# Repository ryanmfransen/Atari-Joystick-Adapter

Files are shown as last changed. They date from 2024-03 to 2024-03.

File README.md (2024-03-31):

# Atari Joystick Adapter
A bluetooth adapter for the Atari CX-40 joysticks

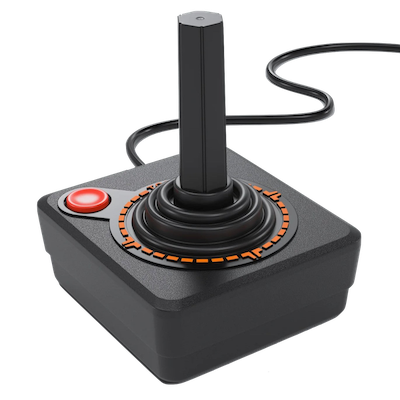
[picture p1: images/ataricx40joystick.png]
Atari CX-40 Joystick


## Finished Product

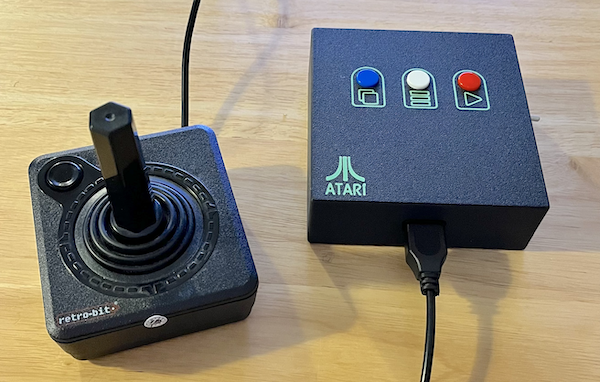
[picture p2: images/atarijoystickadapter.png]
Atari Joystick Adapter


## Design Objectives
You might ask why I would build such a project. With the proliferation of existing gamepads, retro tech, and alternatives, what is it about this that makes it unique?

Fair question. To begin, let's roll back the clock. I used to have all the old systems, and when I wanted to play any of the retro machines, I would simply toss in the cartridge and play away, just like when I was a kid.

I've since sold my collection of retro game machines and recently got into emulation. Emulation affords me the opportunity to still play the old school games yet be able to do so on a single, modern appliance. 

This is great, except for one thing; The joysticks.

I miss playing games as they were intended. It just isn't the same thing playing Space Invaders on the Atari 2600 with the classic joystick as it is playing it on an emulator with a modern XBox controller.  Yes, it works fine, but the experience is not the same.

The Atari Joystick Adapter was born. *I wanted a way to use my classic joysticks the way the games were designed for while playing emulation.*
## Design Goals
**Classic Joysticks**

I wanted to be able to use my existing class joysticks without modification.

**Wireless**

The adapter needed to be wireless, so I can sit back on my couch and play games without being tethered to an appliance.

**Emulator Navigation**

I needed ther ability to navigater, and control the emulator with the classic joystick such that I could select, launch and play games without the use of another controller, remote, or keyboard.

**Additional Game System Buttons**

I needed the ability to mimic the buttons on the original Atari to begin playing games - Start for example.

**Battery Operated**

To be truly wireless, I needed to make this a battery operated device, and be able to charge the device simply by plugging in a USB-C cable such as is with modern rechargeable devices.

**Professional**

Yeah yeah I know, this is a one off device but I want it to look professional, with a custom PCB, and a good looking multicolour 3D printed enclosure.

## The PCB

I designed the circuit using KiCad. I designed most of the symbols, and footprints, sans the simple capacitor, resistor, and connectors. I think I also grabbed the ESP32 symbol from somewhere. The schematics and the KiCad project files can be found here: [Atari Joystick Adapter KiCad Project](kicad/)

Schematic:

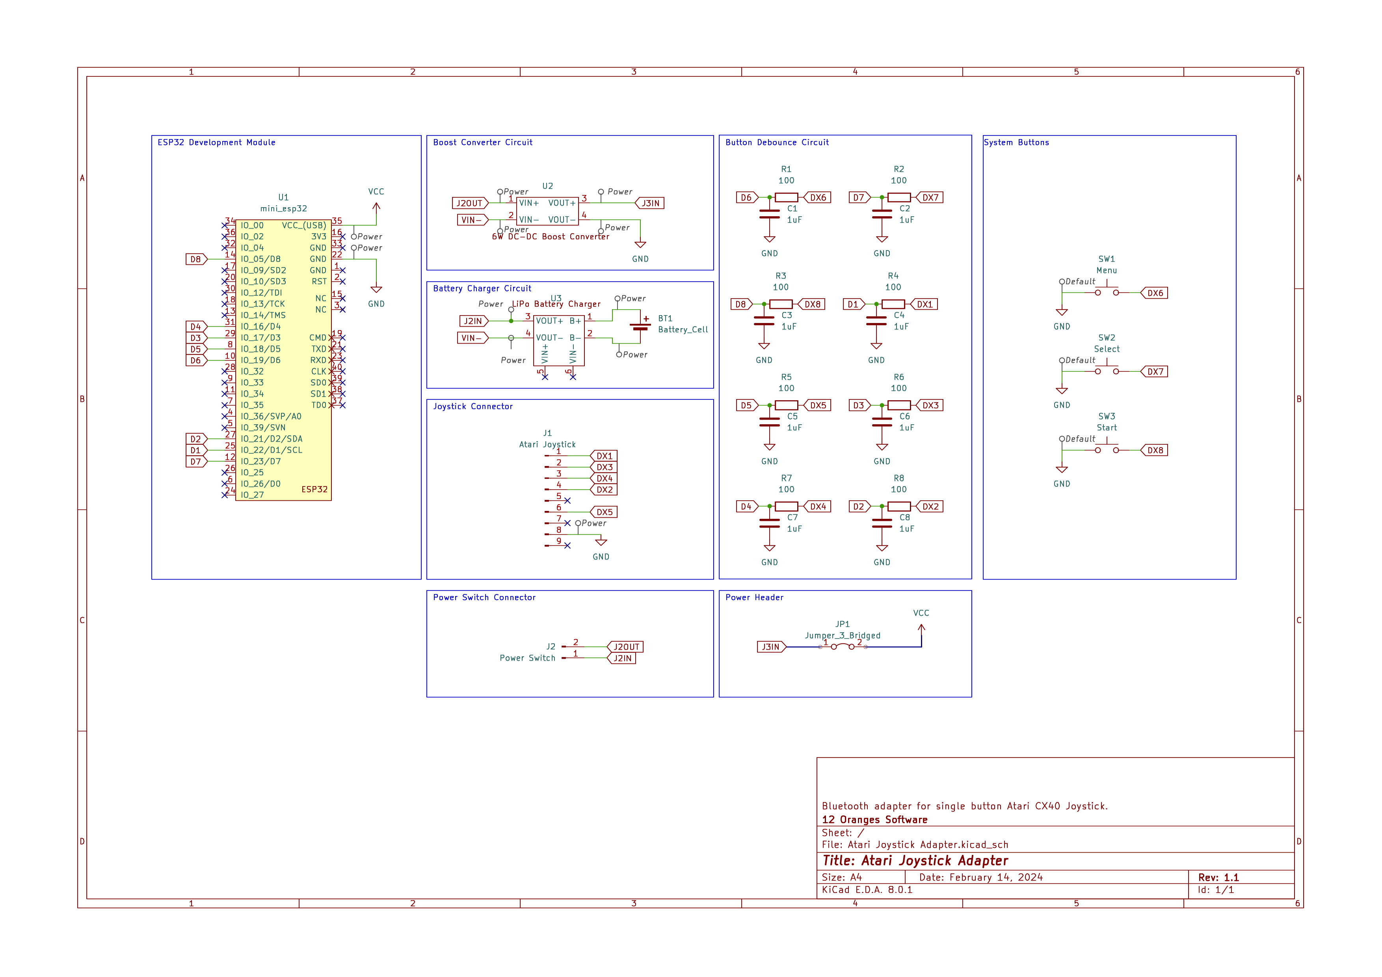
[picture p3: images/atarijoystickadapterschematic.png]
Atari Joystick Adapter Schematic


Here is a 3d Render (v1.1):

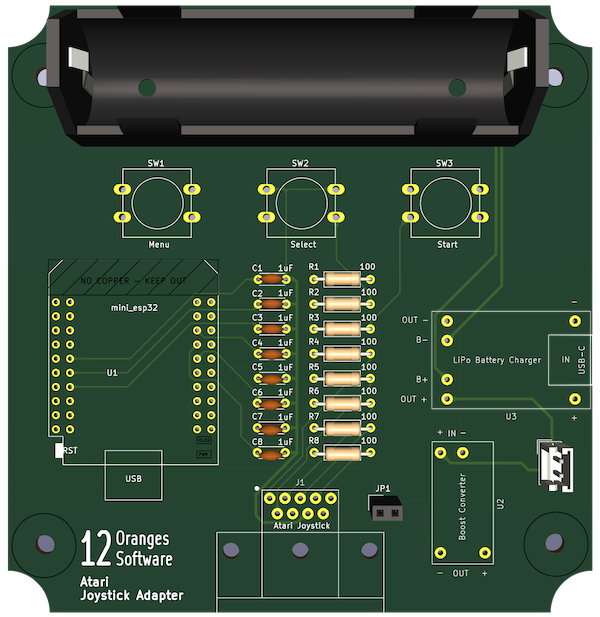
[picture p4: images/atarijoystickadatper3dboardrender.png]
Atari Joystick Adapter 3D PCB Render


Here is a picture of the populated board (v1.0)

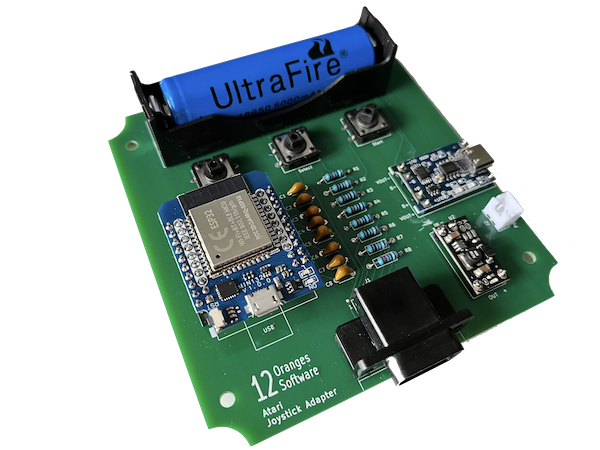
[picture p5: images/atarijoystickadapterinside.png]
Atari Joystick Adapter Inside


I sent the gerber files to PCBWay to be built, and received 10 boards in about a week.

## Interfacing the Atari Joystick

The Atari joystick uses a simple mechanism to manage the four direction buttons and the fire button.  Each button is assigned to a pin on the connector, and when pressed brings the pin low, as is seen from the ground, or common pin on the connector, pin eight(8). This makes it quite easy to connect to the ESP32, all I needed was simple debounce circuits and can otherwise go straight into the digital GPIO pins.

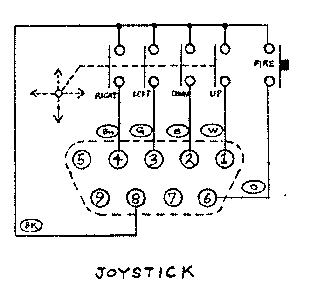
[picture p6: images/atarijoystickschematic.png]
Atari Joystick Schematic


## The Atari Connector

I recall back in the seventies and eighties we used to use standard DB9 serial connectors when we were making Atari style joysticks or interfacing to them. While these don't quite fit perfectly, they do work well. For this project I wanted to finally make use of real Atari joystick connectors, so I found a source for them in San Jose, Best Electronics, and bough 20 of them.

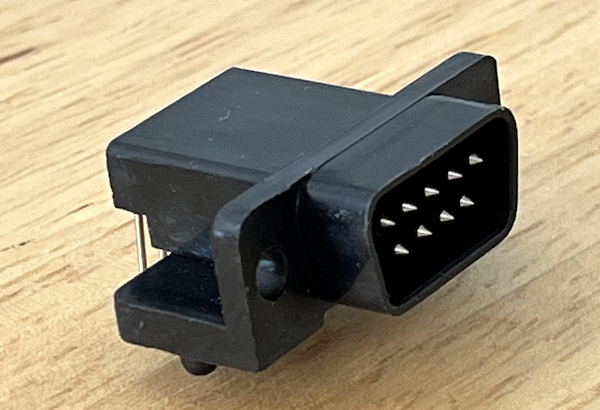
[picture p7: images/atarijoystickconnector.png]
Atari Joystick Connector


I've also modelled the Atari joystick connector in CAD.  Mostly just to help facilitate designing the enclosure for fitment, however I also added it to the KiCad footprint so you could also render the 3d model of the PCB with it as well.

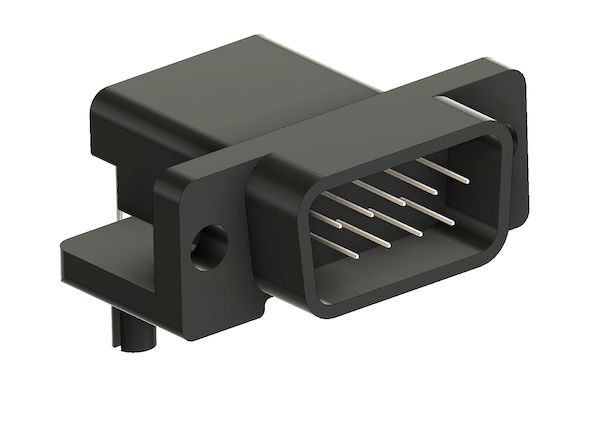
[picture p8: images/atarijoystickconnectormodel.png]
Atari Joystick Connector Model


You can download the model here: [Atari Joystick Connector Model](models/atarijoystickmodel.step)

## ESP32

I ended up using the ESP32 Mini WROOM-32 by KeeYees.  I really like the mini board configuration, as I have used several of the similar D1Minis ESP8266's in the past.

The ESP32 dev board was the obvious choice for this project as it has the bluetooth connectivity I need and sufficient GPIO pins.

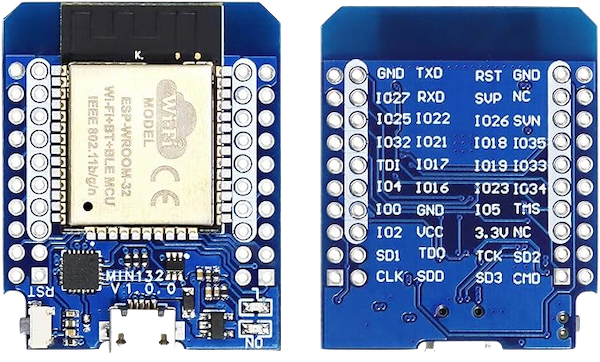
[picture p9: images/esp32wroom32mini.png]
ESP32 Mini


I used this ESP32 from Amazon: [ESP32 Mini Wroom-32](https://www.amazon.ca/gp/product/B08TBQRMY4)

## Battery and Battery Charging

One of my design goals was to use a rechargeable battery and circuit.  I had a bunch of 18650 batteries around for other projects, so that seemed like it would be a good fit for this project.  I would have to settle on a charging circuit, and I could obtain a TC4056 Lithium Battery Charger Module Board from Amazon for quite cheap.  This would more than suffice for what I needed.  The ESP32 uses a 5V input, so I needed to deal with this, as the 18650 has a 3.7v output, which does diminish during it's charge/release cycle.  A simple DC-DC 6W Mini Step-Up Boost Converter would do the trick, and boost me up to 5V, regardless of the diminishing voltage. Perfect - Both these parts are cheap and easily available.

At this point all I had to do was throw a switch into the power circuit and that should solve my power requirements. Done.

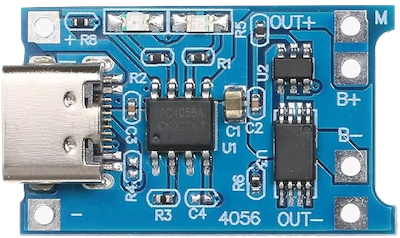
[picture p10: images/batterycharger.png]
Battery Charger


I purchased this [Battery Charger](https://www.amazon.ca/gp/product/B0B48VWHTD) from Amazon

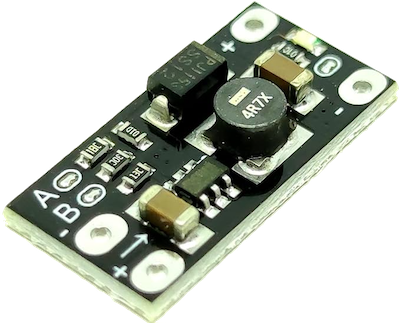
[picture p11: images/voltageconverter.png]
Volage Converter


I purchased this [Boost Converter](https://www.amazon.ca/gp/product/B09TZSGHYK) from Amazon

## Enclosure

I designed the enclosure in Autodesk's Fusion 360. I think it worked out quite well.  The enclosure consists of the main(top) piece, and the cover (bottom) as well as three switch extensions so you can use the three switches placed in the PCB such that they would extend the proper amount up and out of the top case.

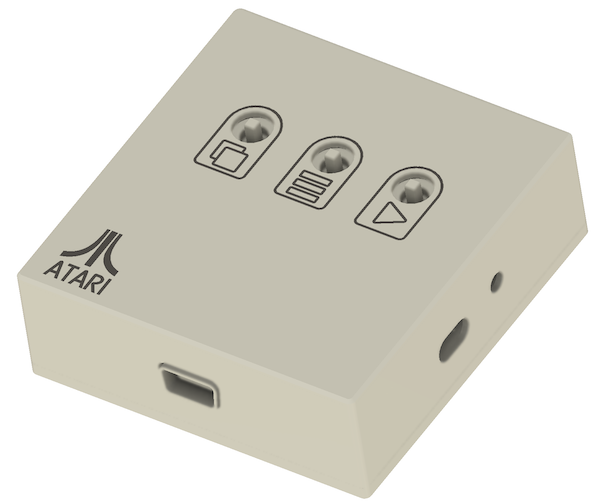
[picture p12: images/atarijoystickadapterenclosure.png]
Atari Joystick Adapter Enclosure Rendering


The enclosure CAD files can be found here: [Atari Joystick Adapter CAD Files](models)

The Bambu Studio .3mf file for the enclosure can be found here: [Atari Joystick Adapter Bambu Studio 3mf Project File](bambustudio/Atari%20Joystick%20Adapter%20Case.3mf)

## The Code

I built the code for this project in C++ using Visual Studio Code and PlatformIO, with the Arduino Framework.  I make use the GamepadBLE library by lemmingDEV, found here: [ESP-32-BLE-Gamepad](https://github.com/lemmingDev/ESP32-BLE-Gamepad)

I use a number of classes to manage the program.  The main class is the Button class.  The Button class encapsulates everything needed to support using buttons on your retro joysticks. It will store the current button state, whether the state has changed, which ESP32 GPIO pin the button is assigned to, and it handles the hardware interrupt callback for that button.  Each button manages it's own interup handler to encapsulate the interrupt logic. This class is used for the joystick, or d-pad (hat) direction buttons.

The second Class is the FireButton class, extending the Button class.  This adds in the addition of a button identifier, used for gamepad buttons, such as the fire button.

The interrupt service routines, in the button objects simply set the updated state, and flag the button as having changed state.

Managing the interrupt handler in each object is a handy way to control state. Most solutions I have seen out on Youtube have some sort of global variables storing the state for all the buttons.  I like the ability to do this atomically, it keeps things clean.

Here is the Button class initializer function, setting the ISR for the class instance.
```
void Button::init() {
  // Set the pin to input and use a pullup resistor
  pinMode(pin, INPUT_PULLUP);

  // Set the current state of the pin
  this->state = LOW;

  // Let's attach the interrupt handler
  std::function<void(void)> stdFunct {std::bind(&Button::instanceIsr, this)};
  attachInterrupt(digitalPinToInterrupt(this->pin), stdFunct, CHANGE);
}
```

The main loop of the application simply iterates over the button instances, checking if they have changed state.  If they have, then the new state is sent via the bluetooth gamepad.

The project code and all source files are included for you.

This project was built to accommodate the four joystick direction buttons, the single joystick fire button, as well as three additional buttons to support game system and emulator navigation and control.

The joystick direction buttons are mapped to the four hat buttons in the gamepad emulation.  The possible states are:

```
  LEFT_UP:8     UP:1          UP_RIGHT:2 
  ⎡    ▲    ⎤   ⎡    ▲    ⎤   ⎡    ▲    ⎤
  ⎢    0    ⎟   ⎢    0    ⎟   ⎢    0    ⎟
  ⎢◀︎ 0   1 ▷⎟   ⎢◁ 1   1 ▷⎟   ⎢◁ 1   0 ▶︎⎟
  ⎢    1    ⎟   ⎢    1    ⎟   ⎢    1    ⎟ 
  ⎣    ▽    ⎦   ⎣    ▽    ⎦   ⎣    ▽    ⎦ 
  
  LEFT:7        CENTERED:0    RIGHT:3
  ⎡    △    ⎤   ⎡    △    ⎤   ⎡    △    ⎤
  ⎢    1    ⎟   ⎢    1    ⎟   ⎢    1    ⎟
  ⎢◀︎ 0   1 ▷⎟   ⎢◁ 1   1 ▷⎟   ⎢◁ 1   0 ▶︎⎟
  ⎢    1    ⎟   ⎢    1    ⎟   ⎢    1    ⎟
  ⎣    ▽    ⎦   ⎣    ▽    ⎦   ⎣    ▽    ⎦
  
  DOWN_LEFT:6   DOWN:5        DOWN_RIGHT:4
  ⎡    △    ⎤   ⎡    △    ⎤   ⎡    △    ⎤
  ⎢    1    ⎟   ⎢    1    ⎟   ⎢    1    ⎟ 
  ⎢◀︎ 0   1 ▷⎟   ⎢◁ 1   1 ▷⎟   ⎢◁ 1   0 ▶︎⎟
  ⎢    0    ⎟   ⎢    0    ⎟   ⎢    0    ⎟
  ⎣    ▼    ⎦   ⎣    ▼    ⎦   ⎣    ▼    ⎦
```
Each state is mapped to an integer value, from `0..8` and it is this integer value sent to the gamepad controller to register the d-pad presses in the emulator.

The four buttons are buttons `1..4`, and are typically registered, depending on the system you pair with, as buttons a, b, x, y on the gamepad controller in the emulator.

From here, you can assign each of these four buttons to whatever makes sense for you.  I used:
```
[a], [b], [select], [start]
```

## Emulator

I use Retroarch, and it was a little tricky getting the proper button assignments configured so I could navigate the Retroarch menu, launch the game in the emulator, and then start the game, and play the game all with only using the Atari joystick and the buttons on the adapter.

Once configured, it works incredibly well.

## Did I achieve my Goals?

Yes! I believe so. Let's have a look:
- [x]  Classic Joysticks
- [x]  Wireless
- [x]  Emulator Navigation
- [x]  Additional Game System Buttons
- [x]  Battery Operated
- [x]  Professional

## Observations

1. Latency.  The latency is either incredible, or I am blind to it because I put so much effort into making this. In any event, gameplay is amazing, and very responsive.  I am very happy with the latency given the bluetooth connectivity, and emulation.

2. I actually use this.  Unlike most of my projects which are super fun to build, they usually end up on a shelf, or in a drawer, and I tend to forget about them. This project is different.  I actually is it, and is a lot of fun to play the games wit hthe classic controllers.

## What I Would do Different Next Time

1. Test Points. I would (and have in the v2 board) include test points to troubleshoot the circuit. This just makes things much easier to measure voltages and test your circuits.

2. Power Jumper. Ok, so I have to admit I placed all the parts, soldered everything in, and powered it on.  Of course, I forgot to configure the voltage booster from the default 12v to my required 5v, and I fried my brand new ESP32. 
 I've since added a two pin jumper that needs to be in place for the power to get to the ESP32, this way I can power the board up and test the circuit power without destroying the ESP.

3. My first prototype had the ESP32 soldered directly to the board, and while offers a nice finished product, see point 2 above, and I needed to remove it, so prototype two I put headers in and as you can see from the picture, the ESP32 is now removable, if ever needed.

4. While the 18650 works well, I might source a small flat pack lithium ion battery. The package is much smaller and will have plenty of power for what I need.  Would also remove the need for the battery holder I had to source.

## Next Steps

1. Driving Controller. I would like to support the Atari driving controller used for games like Indy 500.

2. Paddle Controllers. I would also like to support the Atari paddle controllers used for games like Super Breakout or Warlords.

3. Sega or Nintendo Controllers. Might be nice to extend this to use the controllers using shift registers or other multiplexers. Modern versions of these controllers can be purchased, so uncertain about this.

4. Two Player support. At the moment, this is a device for a single Atari joystick. Perhaps I could extend this to support two joysticks for two player games without requiring two devices.

## Contact Me!

If you would like to discuss the project or have an idea, or question please reach out.  I can be reached at:

`ryan.fransen[the symbol for at]me.com`

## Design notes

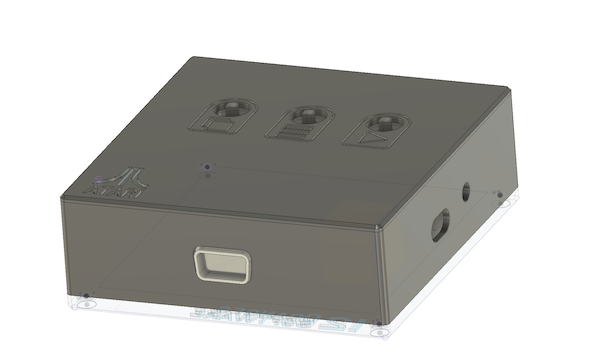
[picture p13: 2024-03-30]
images/atarijoystickadaptercaserender.png

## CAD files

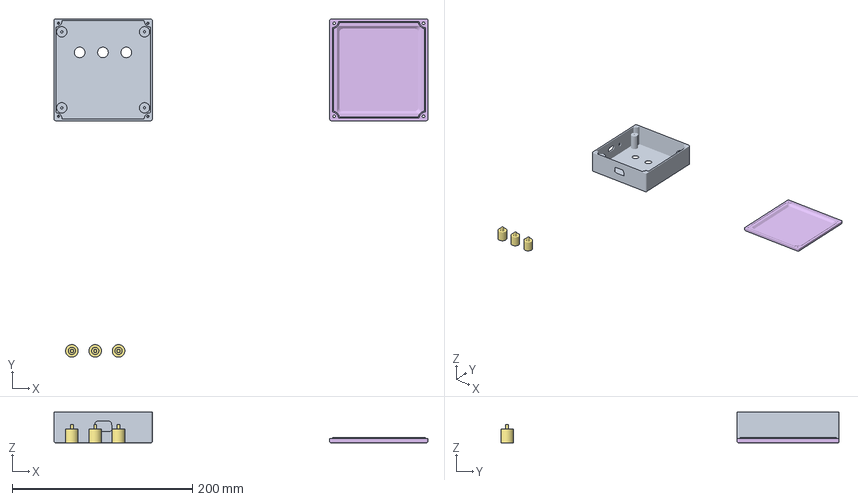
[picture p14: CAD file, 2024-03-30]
bambustudio/Atari Joystick Adapter Case.3mf
415.1 x 375.5 x 34.0 mm
Case Bottom
Menu Button Graphic
Menu Button Container
Atari Logo
12 Oranges Logo (1)
Button Riser

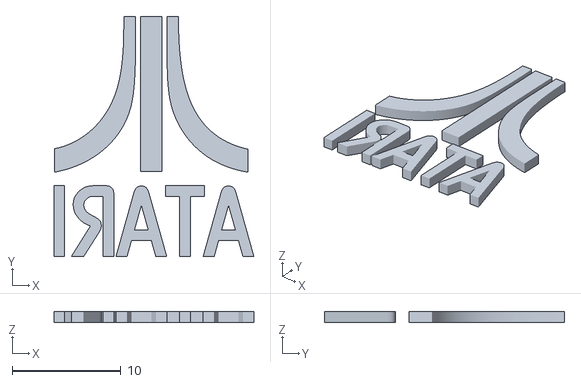
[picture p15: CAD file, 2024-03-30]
models/Atari Logo.stl
18.4 x 22.0 x 1.00

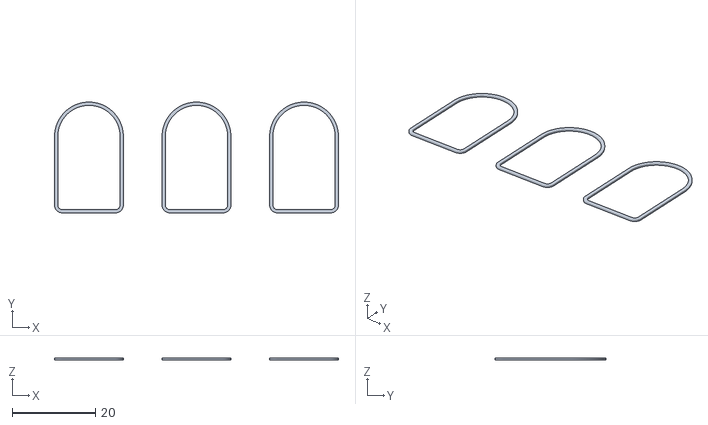
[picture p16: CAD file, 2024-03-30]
models/Menu Button Container.stl
68.4 x 26.7 x 0.5

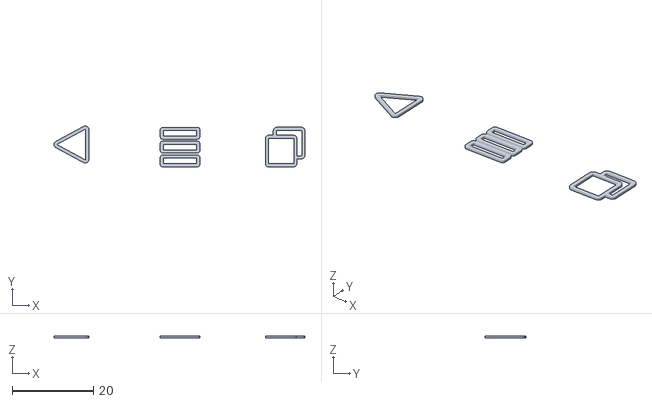
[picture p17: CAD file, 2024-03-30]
models/Menu Button Graphic.stl
61.9 x 10.1 x 0.5

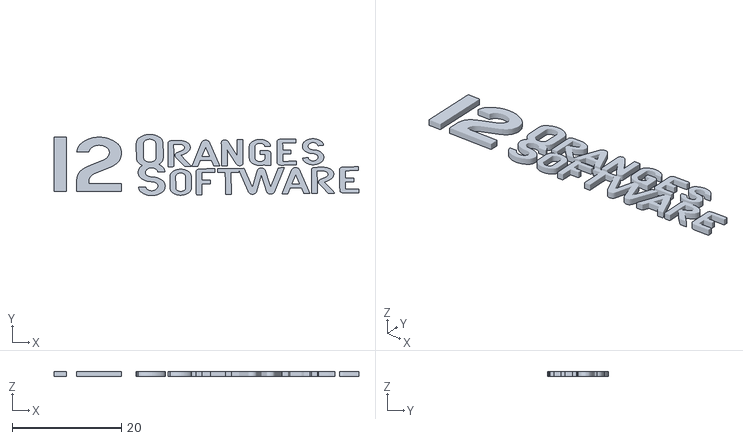
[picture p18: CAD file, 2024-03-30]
models/12 Oranges Logo.stl
55.8 x 11.2 x 1.00

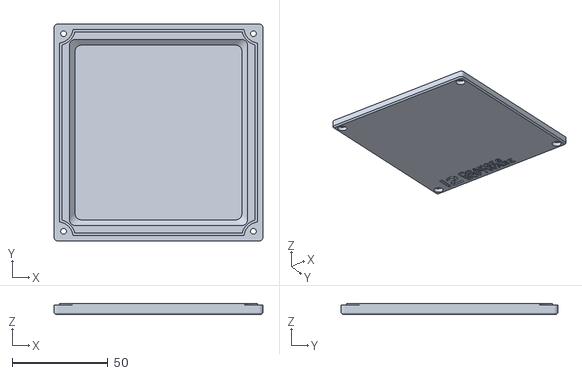
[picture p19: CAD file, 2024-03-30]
models/Case Top.stl
109.1 x 113.2 x 6.00

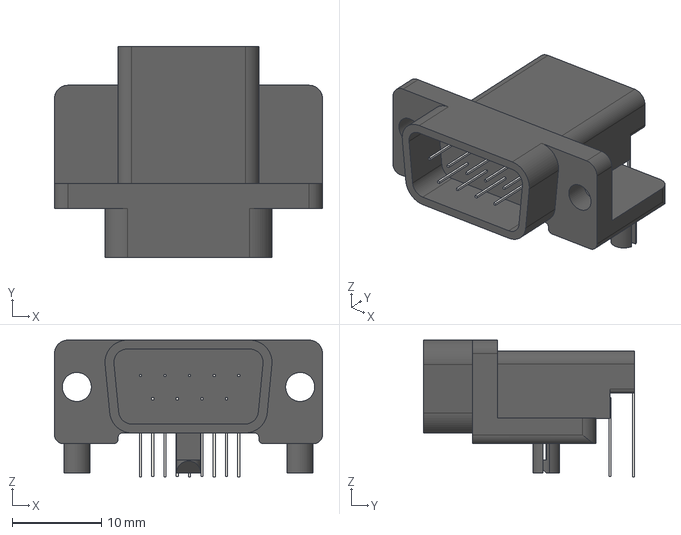
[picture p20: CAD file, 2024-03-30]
models/Atari Joystick Connector.step
30.0 x 23.6 x 15.3 mm

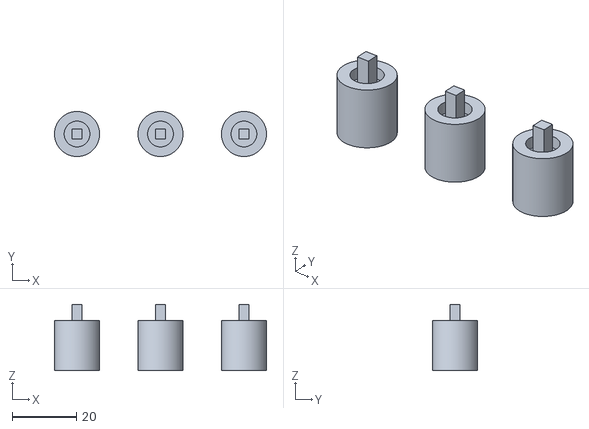
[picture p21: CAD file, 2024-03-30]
models/Button Riser.stl
65.8 x 14.0 x 20.5

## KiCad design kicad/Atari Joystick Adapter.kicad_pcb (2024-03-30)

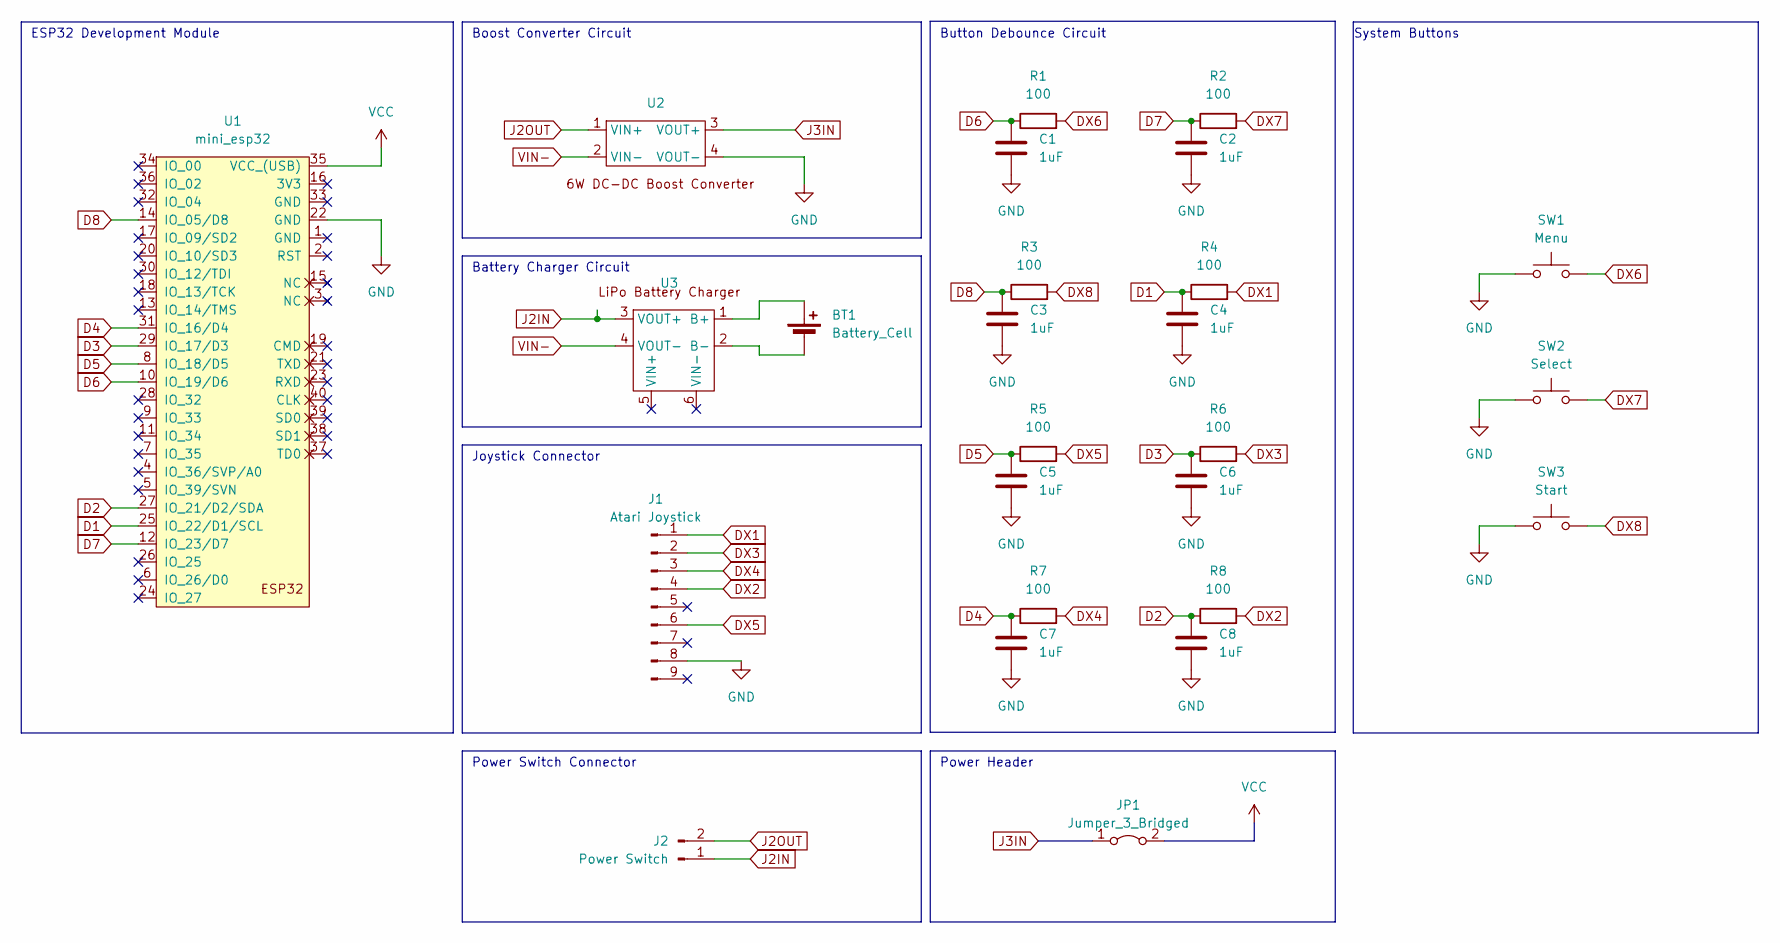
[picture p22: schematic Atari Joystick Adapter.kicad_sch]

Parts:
BT1: Battery_Cell; BatteryHolder_BH-18650
C1, C2, C3, C4, C5, C6, C7, C8: 1uF; C_Disc_D4.3mm_W1.9mm_P5.00mm
J1: Atari Joystick; Atari 9Pin Joystick Connector
J2: Power Switch; JST_EH_B2B-EH-A_1x02_P2.50mm_Vertical
JP1: Jumper_3_Bridged; PinSocket_1x02_P2.54mm_Vertical
R1, R2, R3, R4, R5, R6, R7, R8: 100; R_Axial_DIN0207_L6.3mm_D2.5mm_P10.16mm_Horizontal
SW1: Menu; SW_PUSH-12mm
SW2: Select; SW_PUSH-12mm
SW3: Start; SW_PUSH-12mm
U1: mini_esp32; ESP32_mini
U2: 6W DC-DC Boost Converter
U3: LiPo Battery Charger Circuit

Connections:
D1: C4.1, R4.1, U1.25 (IO_22/D1/SCL)
D2: C8.1, R8.1, U1.27 (IO_21/D2/SDA)
D3: C6.1, R6.1, U1.29 (IO_17/D3)
D4: C7.1, R7.1, U1.31 (IO_16/D4)
D5: C5.1, R5.1, U1.8 (IO_18/D5)
D6: C1.1, R1.1, U1.10 (IO_19/D6)
D7: C2.1, R2.1, U1.12 (IO_23/D7)
D8: C3.1, R3.1, U1.14 (IO_05/D8)
DX1: J1.1, R4.2
DX2: J1.4, R8.2
DX3: J1.2, R6.2
DX4: J1.3, R7.2
DX5: J1.6, R5.2
DX6: R1.2, SW1.2
DX7: R2.2, SW2.2
DX8: R3.2, SW3.2
GND: C1.2, C2.2, C3.2, C4.2, C5.2, C6.2, C7.2, C8.2, J1.8, SW1.1, SW2.1, SW3.1, U1.22 (GND), U2.4 (VOUT-)
J2IN: J2.1, U3.3 (VOUT+)
J2OUT: J2.2, U2.1 (VIN+)
J3IN: JP1.1 (A), U2.3 (VOUT+)
unnamed: BT1.1 (+), U3.1 (B+)
unnamed: BT1.2 (-), U3.2 (B-)
VCC: JP1.2 (B), U1.35 (VCC_(USB))
VIN-: U2.2 (VIN-), U3.4 (VOUT-)

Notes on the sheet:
Button Debounce Circuit
ESP32 Development Module
System Buttons
Boost Converter Circuit
Power Header
Battery Charger Circuit
Joystick Connector
Power Switch Connector

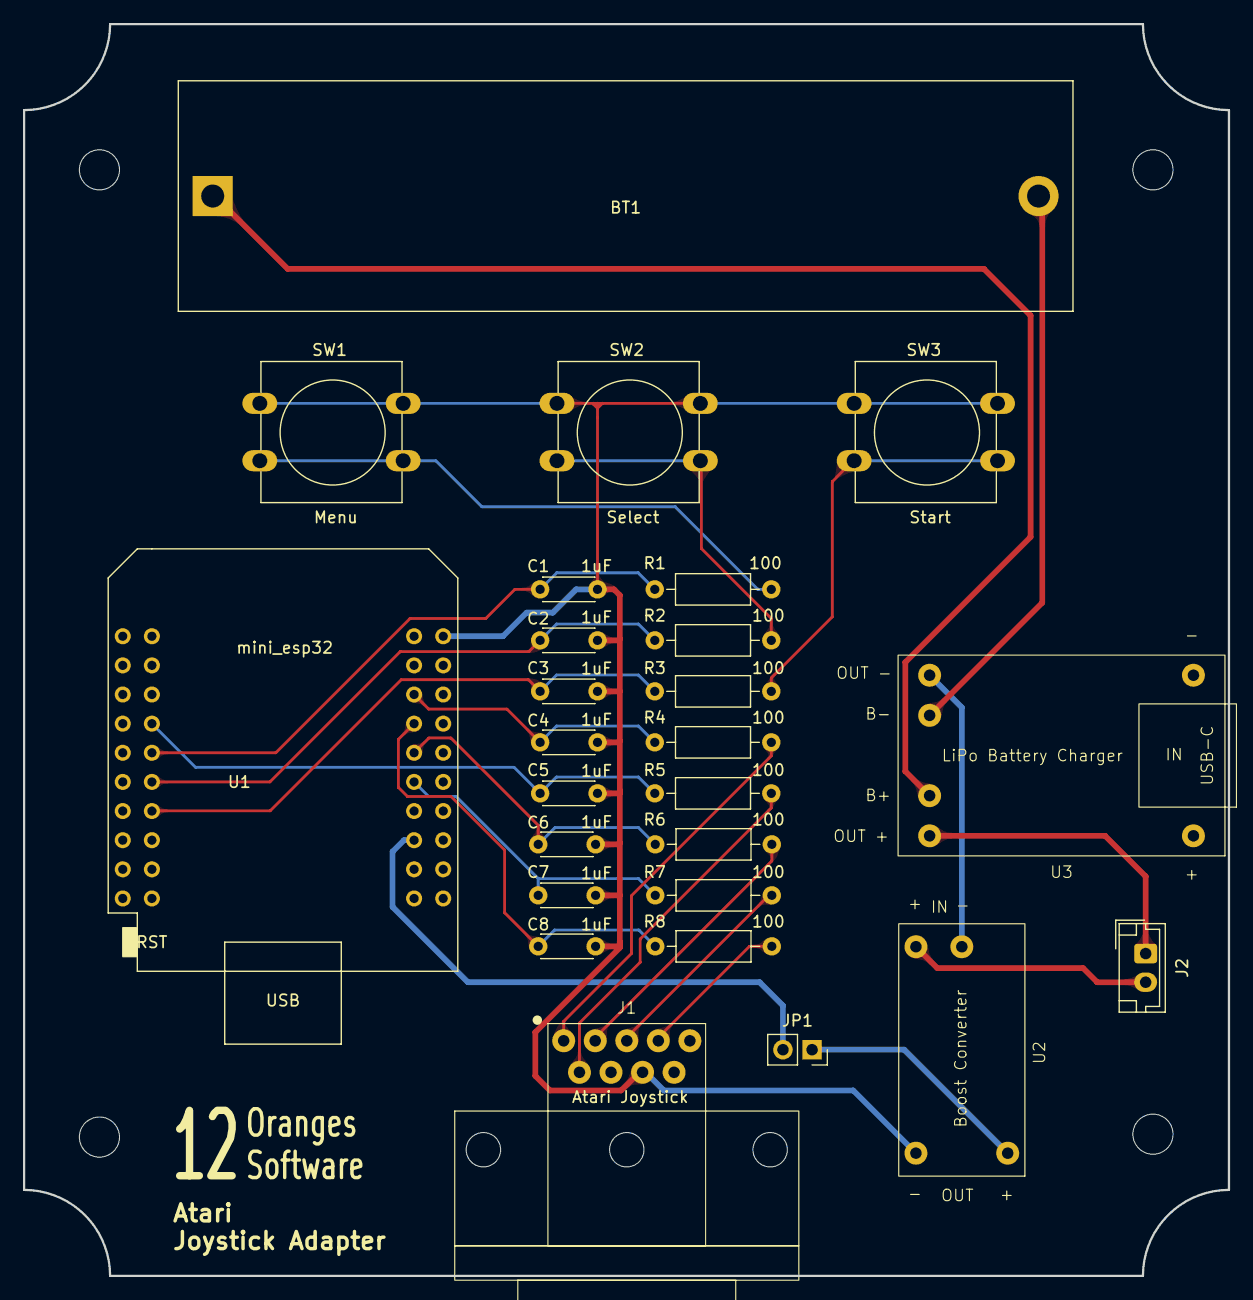
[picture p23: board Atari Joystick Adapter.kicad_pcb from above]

Board: 2 copper layers, 105.0 x 109.1 mm, 30 parts (0 on the bottom side), 24 nets.

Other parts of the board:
H1, H2, H3, H4: MountingHole; MountingHole_3.5mm

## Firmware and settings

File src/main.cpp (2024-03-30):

/*
 * Author:    Ryan Fransen
 * Created:   February, 10, 2024
 * Version:   1.0
 * 
 * Atari
 * Joystick Adapter
 * {{UP, RIGHT, DOWN, LEFT}, FIRE, (Additional Buttons 2, 3, 4)}
 * 
 * main.cpp
 *
 * 
 * Atari Joystick Adapter. This program reads in the button states of an Atari joystick and
 * converts those button presses into a Bluetooth gamepad controller.
 * 
 * The four directions on the joystick are mapped to the gamepads D-pad buttons, or hats.
 * The fire button maps to the gamepad button 1. Three additional buttons are included to manage
 * additional buttons used for the emulator and can be used to control buttons on the game system itself.
 * 
 * The program uses hardware interupts to detect button presses.
 * 
 */

#include <Arduino.h>
#include <BleGamepad.h>

#include "deviceinfo.hpp"
#include "button.hpp"
#include "firebutton.hpp"

// Joystick Fire Button id's
uint8_t joystick_fire_button_1 = 1;
uint8_t joystick_fire_button_2 = 2;
uint8_t joystick_fire_button_3 = 3;
uint8_t joystick_fire_button_4 = 4;

// Joystick direction GPIO Pins
const int joystick_up_pin    = D1;
const int joystick_right_pin = D2;
const int joystick_down_pin  = D3;
const int joystick_left_pin  = D4;

// Joystick Fire Button GPIO Pins
const int joystick_fire_button_pin_1 = D5;
const int joystick_fire_button_pin_2 = D6;
const int joystick_fire_button_pin_3 = D7;
const int joystick_fire_button_pin_4 = D8;

// Battery level
const int battery_level = 100;

// Joystick d-pad hat state map. We'll use this to determine the hat value to send.
// based on the d-pad switch states
int hat_map[2][2][2][2];

// Let's map the button indexes
const uint8_t BUTTON_UP    = 0;
const uint8_t BUTTON_RIGHT = 1;
const uint8_t BUTTON_DOWN  = 2;
const uint8_t BUTTON_LEFT  = 3;

// D-Pad buttons
std::vector<Button> joystick_direction_buttons = {
  Button(joystick_up_pin),
  Button(joystick_right_pin),
  Button(joystick_down_pin),
  Button(joystick_left_pin)
};

// Fire buttons
std::vector<FireButton> joystick_fire_buttons = {
  FireButton(joystick_fire_button_pin_1, joystick_fire_button_1),
  FireButton(joystick_fire_button_pin_2, joystick_fire_button_2),
  FireButton(joystick_fire_button_pin_3, joystick_fire_button_3),
  FireButton(joystick_fire_button_pin_4, joystick_fire_button_4)
};

// Gamepad constructor
BleGamepad gamepad(
  DeviceInfo::getName(), 
  DeviceInfo::getManufacturer(), 
  DeviceInfo::getBbatteryLevel());

/*
 * Function: set_hat_map
 * ---------------------
 * Initializes the hat map. The hat map is used to set the value to send for each of the hat button values.
 * We send a single byte value which represents the state of the hat, including all four hat buttons.
 * 
 * We'll use a four dimension two element array to map the values.  This makes it easy to
 *  take the pin values from the four direction buttons to determine the hat value to send, 0-8, per below.
 * 
 * In order: CENTERED[0], UP[1], UP_RIGHT[2], RIGHT[3], DOWN_RIGHT[4], DOWN[5], DOWN_LEFT[6], LEFT[7], UP_LEFT[8]
 * 
 * LEFT_UP:8     UP:1          UP_RIGHT:2 
 * ⎡    ▲    ⎤   ⎡    ▲    ⎤   ⎡    ▲    ⎤
 * ⎢    0    ⎟   ⎢    0    ⎟   ⎢    0    ⎟
 * ⎢◀︎ 0   1 ▷⎟   ⎢◁ 1   1 ▷⎟   ⎢◁ 1   0 ▶︎⎟
 * ⎢    1    ⎟   ⎢    1    ⎟   ⎢    1    ⎟ 
 * ⎣    ▽    ⎦   ⎣    ▽    ⎦   ⎣    ▽    ⎦ 
 * 
 * LEFT:7        CENTERED:0    RIGHT:3
 * ⎡    △    ⎤   ⎡    △    ⎤   ⎡    △    ⎤
 * ⎢    1    ⎟   ⎢    1    ⎟   ⎢    1    ⎟
 * ⎢◀︎ 0   1 ▷⎟   ⎢◁ 1   1 ▷⎟   ⎢◁ 1   0 ▶︎⎟
 * ⎢    1    ⎟   ⎢    1    ⎟   ⎢    1    ⎟
 * ⎣    ▽    ⎦   ⎣    ▽    ⎦   ⎣    ▽    ⎦
 * 
 * DOWN_LEFT:6   DOWN:5        DOWN_RIGHT:4
 * ⎡    △    ⎤   ⎡    △    ⎤   ⎡    △    ⎤
 * ⎢    1    ⎟   ⎢    1    ⎟   ⎢    1    ⎟ 
 * ⎢◀︎ 0   1 ▷⎟   ⎢◁ 1   1 ▷⎟   ⎢◁ 1   0 ▶︎⎟
 * ⎢    0    ⎟   ⎢    0    ⎟   ⎢    0    ⎟
 * ⎣    ▼    ⎦   ⎣    ▼    ⎦   ⎣    ▼    ⎦
 * 
*/
void set_hat_map() {
  hat_map[1][1][1][1] = HAT_CENTERED;   // △ ▷ ▽ ◁
  hat_map[0][1][1][1] = HAT_UP;         // ▲ ▷ ▽ ◁ 
  hat_map[0][0][1][1] = HAT_UP_RIGHT;   // ▲ ▶︎ ▽ ◁ 
  hat_map[1][0][1][1] = HAT_RIGHT;      // △ ▶︎ ▽ ◁ 
  hat_map[1][0][0][1] = HAT_DOWN_RIGHT; // △ ▼ ▶︎ ◁ 
  hat_map[1][1][0][1] = HAT_DOWN;       // △ ▷ ▼ ◁ 
  hat_map[1][1][0][0] = HAT_DOWN_LEFT;  // △ ▷ ▼ ◀︎
  hat_map[1][1][1][0] = HAT_LEFT;       // △ ▷ ▽ ◀︎
  hat_map[0][1][1][0] = HAT_UP_LEFT;    // ▲ ▷ ▽ ◀︎
}

/*
 * Function: configureGamepad
 * --------------------------
 * Configures the bluetooth gamepad instance. 
 * 
*/
void configureGamepad(BleGamepadConfiguration *gamepad_config) {
  // Set the controller type
  gamepad_config->setControllerType(CONTROLLER_TYPE_GAMEPAD);

  // Auto sending report, instead of manual report
  gamepad_config->setAutoReport(true);

  // Set the button count
  gamepad_config->setButtonCount(joystick_fire_buttons.size());

  // Set the count, d-pads are configured as hats in the library
  gamepad_config->setHatSwitchCount(1);

  // Configure the device settings
  gamepad_config->setModelNumber(DeviceInfo::getModelNumber());
  gamepad_config->setSoftwareRevision(DeviceInfo::getSoftwareRevision());
  gamepad_config->setSerialNumber(DeviceInfo::getSerialNumber());
  gamepad_config->setFirmwareRevision(DeviceInfo::getFirmwareRevision());
  gamepad_config->setHardwareRevision(DeviceInfo::getHardwareRevision());
}

/*
 * Function: setup
 * ---------------
 * The main application function.  Executes once at startup.
 * 
*/
void setup() {
  // Initialize the direction Button instances
  for (Button &button : joystick_direction_buttons) {
    button.init();
  }

  // Initialize the Button instances
  for (FireButton &button : joystick_fire_buttons) {
    button.init();
  }

  // Set the hat map values
  set_hat_map();

  BleGamepadConfiguration gamepad_config;

  // Configure the gamepad
  configureGamepad(&gamepad_config);

  // Start the Task service
  gamepad.begin(&gamepad_config);
}

/*
 * Function: loop
 * --------------
 * The main application service loop
 * 
*/
void loop() {

  /* The main loop of the program.
   * All we do in here is check if the joystick button state flags are marked as changed.
   * We maintain state inside the button objects, then when those states are detected in here,
   * we will update the gamepad controller accordingly, and reset the state changed flag. This ensures
   * we are not continuously reading the digital pins and sending data over bluetooth, as we only want to
   * send data when something has changed, either a button was pressed or a button was released.
  */
  if (gamepad.isConnected()) {  
    // Check if the joystick fire buttons have changed state
    for (FireButton &button : joystick_fire_buttons) {
      if (button.getStateChanged()) {
        button.resetStateChanged();
        if (button.getState()) {
          gamepad.release(button.getButtonId());
        } else {
          gamepad.press(button.getButtonId());
        }
      }
    }

    // Check if the joystick direction buttons have changed state
    for (Button &button : joystick_direction_buttons) {
      if (button.getStateChanged()) {
        button.resetStateChanged();
        gamepad.setHat1(hat_map
          [joystick_direction_buttons[BUTTON_UP].getState()]
          [joystick_direction_buttons[BUTTON_RIGHT].getState()]
          [joystick_direction_buttons[BUTTON_DOWN].getState()]
          [joystick_direction_buttons[BUTTON_LEFT].getState()]
        );
      }
    }
  }
}

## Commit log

2024-03-30 Initial commit.
    [12 Oranges Logo.stl, Atari Joystick Adapter Case.3mf, Atari Joystick Adapter.kicad_pcb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]
2024-03-30 Updated readme with pcb and esp32 info.
2024-03-30 Updated readme with enclosure render.
2024-03-30 Updated readme with enclosure info.
